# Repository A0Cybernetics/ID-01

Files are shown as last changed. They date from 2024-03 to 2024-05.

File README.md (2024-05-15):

# A0 Cybernetics: ID-01
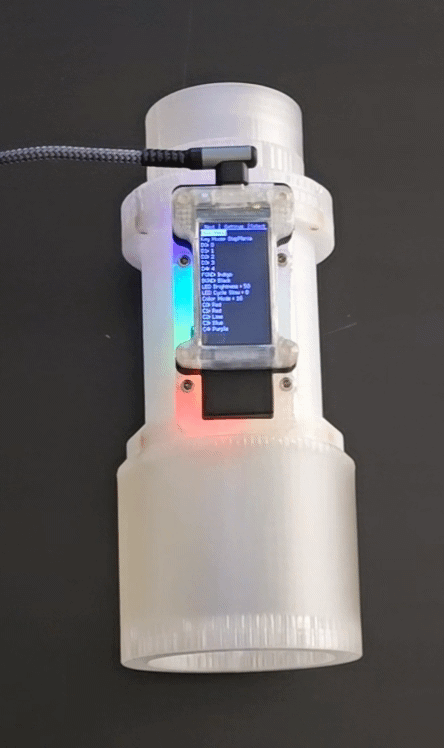
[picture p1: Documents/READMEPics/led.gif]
LEDs
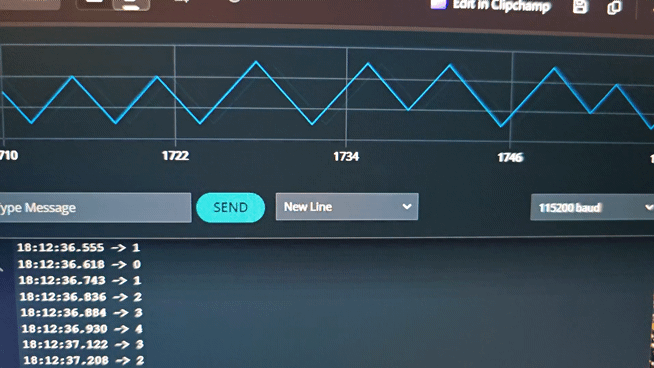
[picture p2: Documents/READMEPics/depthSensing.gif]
Depth Sensing In Action


An interactive adult entertainment device and fitness tracker. It measures a user's position within the device and can transmit commands to connected devices via USB and/or Bluetooth communication. Use data is tracked as key presses for the keys on the device, converted into XP (experience points), and can be saved over the life of the device. Build experience, control other devices, and interact with media.

- Free and open source. I do this because I like it <3

- Onboard TFT screen with UI

- Play any game. Each key can be mapped to 99 different ASCII characters in the settings.

- 21 user-customizable LED lighting modes

- Hot-swappable Cherry MK style keyboard keys for user customization

- No programming or design knowledge is necessary to build

- Open-source and reprogrammable firmware running on ESP32-S3

- Compiled binary files are provided, so there is no need to compile the program.

- Fully 3D-printed parts (except for electrical components, heat set inserts, and screws)

- Multiple designs and customization pieces are provided to accommodate sleeves from Fleshlight and other more affordable options.

- Read the [Build Guide](Documents/buildGuide.txt) for a parts list and fully detailed step-by-step instructions.

## Upgraded Fleshlight End Caps

Multiple designs are provided for end caps for this device or a regular fleshlight.

- ARRI version has a central hole pattern compatible with 1/4"-20 ARRI locating pin camera rigging equipment.

- Ultimate version has the ARRI version pattern in the center and 7 additional 1/4"-20 screw points arranged in a geometric pattern that is compatible with camera cheese plate layouts or whatever you can imagine.

- One is a replacement for the original.

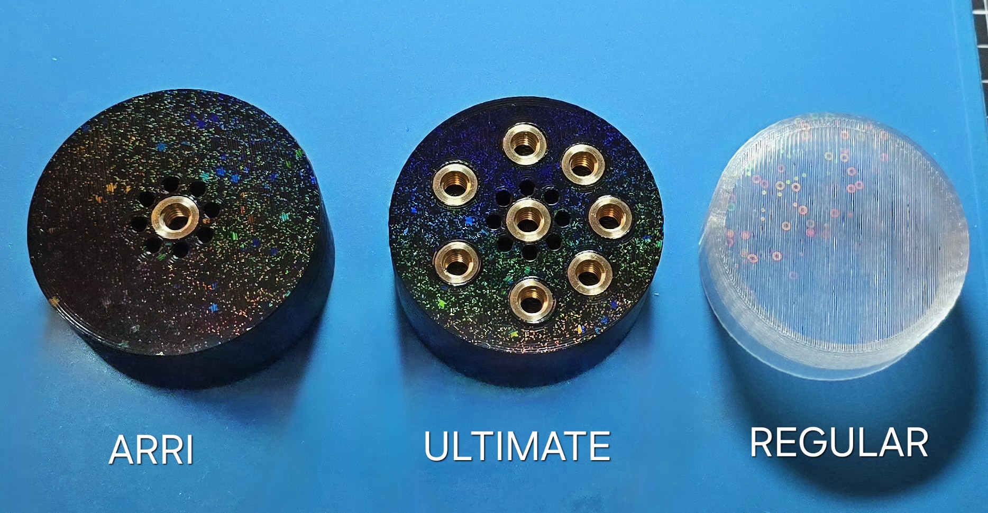
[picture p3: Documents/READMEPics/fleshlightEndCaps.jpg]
Fleshlight End Caps
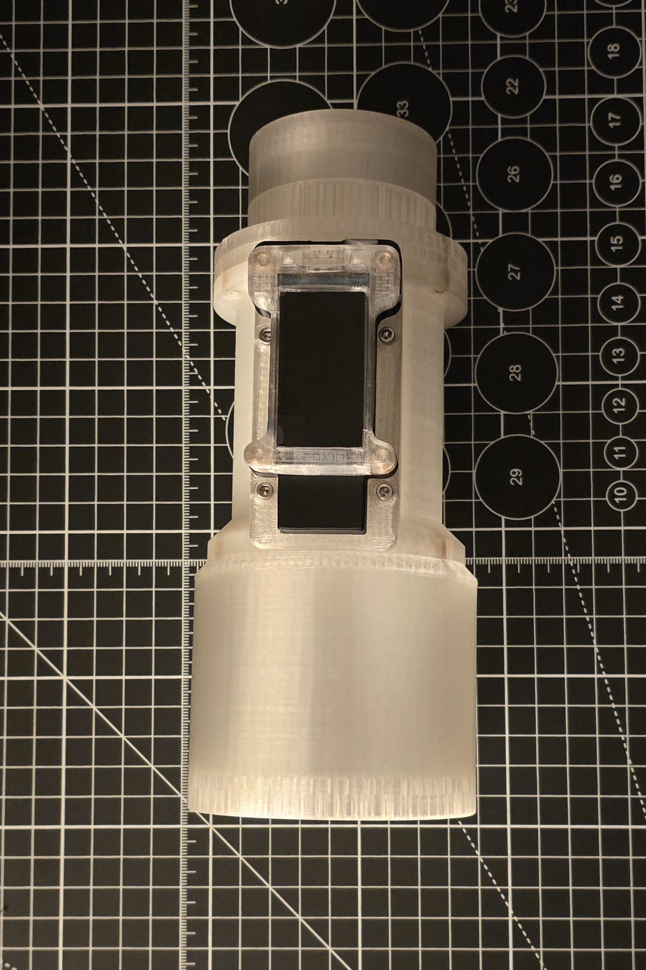
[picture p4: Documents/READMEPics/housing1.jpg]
Flesh1ight Style Housing
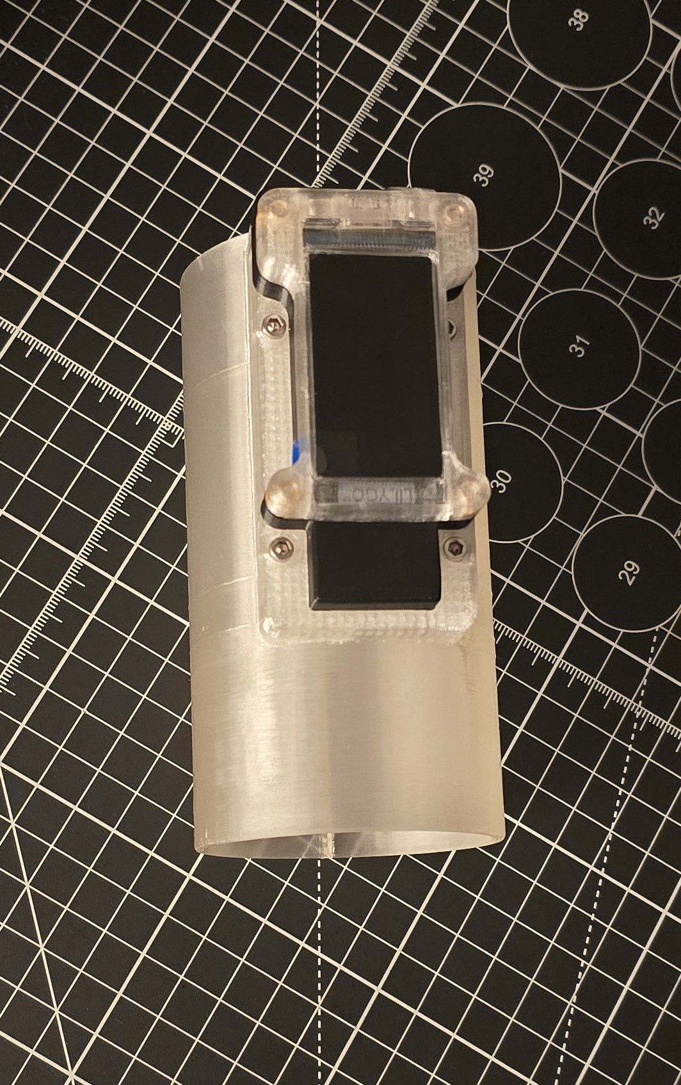
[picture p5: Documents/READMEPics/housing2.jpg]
Generic Style Housing


## Project OutFox / StepMania Compatibility

Play rhythm games with your adult toy. Insert to different depths to hit notes in sync with a rhythm game like DDR.

1. Download a version of StepMania like Project OutFox  projectoutfox.com. (no affiliation)
2. Download song packs and add them to the Project Outfox Songs folder. Search the internet for StepMania song packs.
3. Set up the game and controller as below, and most songs should be playable, but some difficult songs may be physically impossible to perform.

To use this as a controller to play Stepmania:
- On device:
	- In setting, ensure that key mode is set to StepMania. (is the default in firmware)
	- In the Main Menu, turn on BLE or USB Keyboard and connect to the computer.

- In Stepmania:
	- On the Map Controller Settings page in a device column, select the key names below then press the button on the device to map the device keys to the game keys:
		- Left -> Key 1 (most shallow key in the device)
		- Down -> Key 2
		- Up -> Key 3
		- Right -> Key 4 (deepest key in the device)
	- Calibrate Audio Sync - Select Calibrate audio sync option and complete the process to tune timing problems.
	- Set modifiers in Player Options to remove pressing more than one button at a time.
		- Press start again after selecting a song before the song starts to open the Player Options Menu
		- Navigate to the Modifiers submenu and select No Jumps on the Remove row
- Done, This will setup the game so that the notes are mapped from left/ most shallow key to right/ deepest key

## License

[MIT](https://choosealicense.com/licenses/mit/)

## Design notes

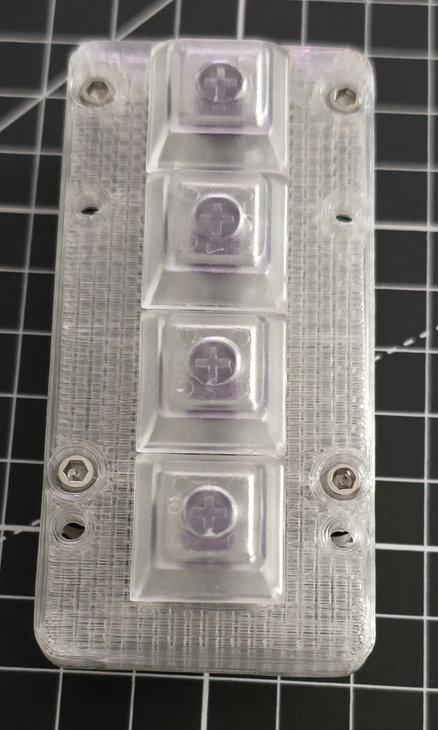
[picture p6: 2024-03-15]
Documents/buildGuidePictures/electronics7.jpg

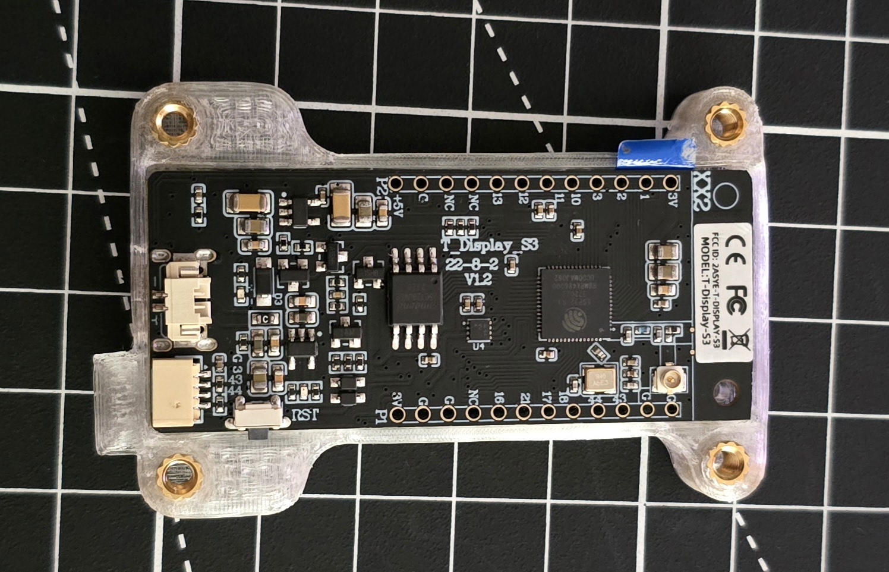
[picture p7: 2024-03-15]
Documents/buildGuidePictures/electronics2.jpg

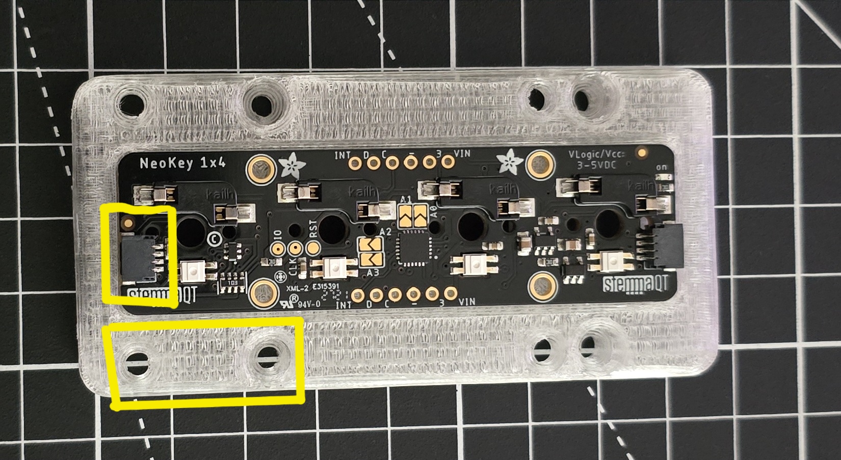
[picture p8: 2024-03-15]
Documents/buildGuidePictures/electronics3.jpg

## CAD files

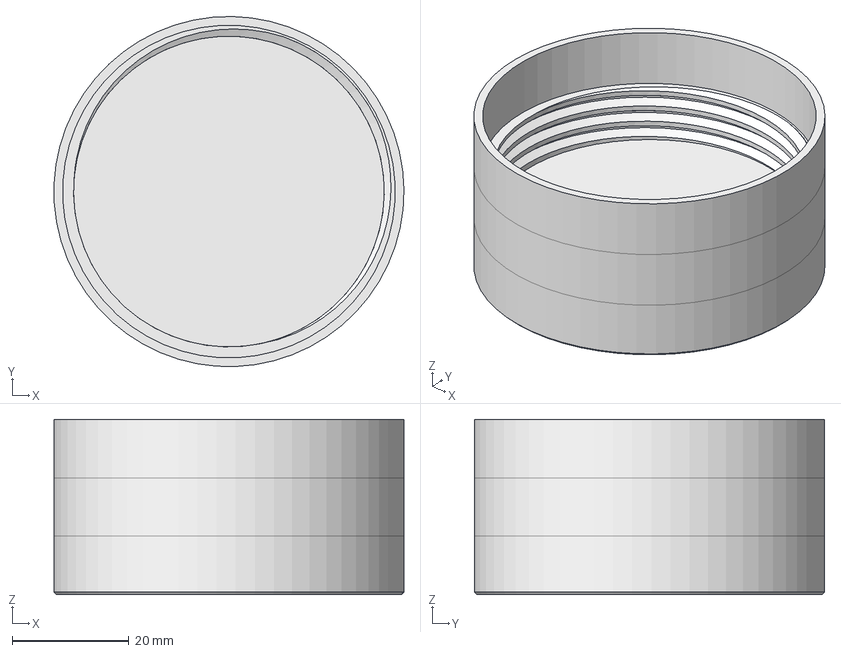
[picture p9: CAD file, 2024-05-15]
3DModels/V1.0/Adapters-FleshlightEndCaps/arriFlEndCapV1.0.FCStd
60.0 x 60.0 x 30.0 mm

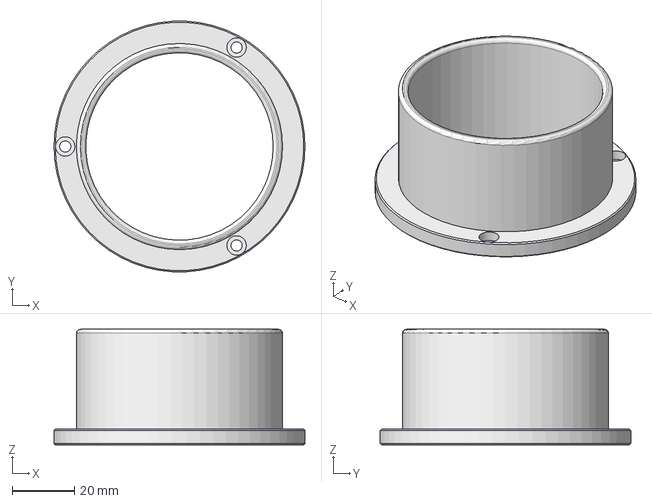
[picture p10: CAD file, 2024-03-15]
3DModels/V1.0/Adapters-Generic/adapterGenericV1.0.FCStd
80.4 x 80.3 x 37.0 mm

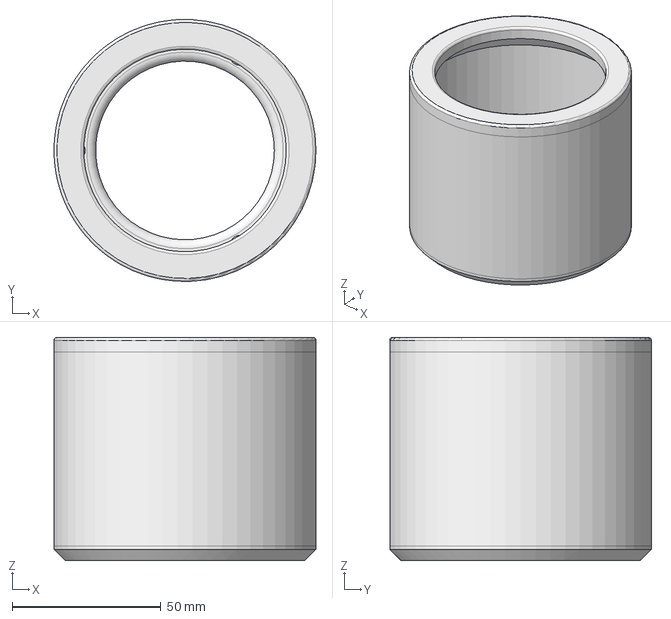
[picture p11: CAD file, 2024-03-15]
3DModels/V1.0/Adapters-LFleshlight/adapterFleshlightV1.0-75mm.FCStd
88.0 x 87.9 x 75.0 mm

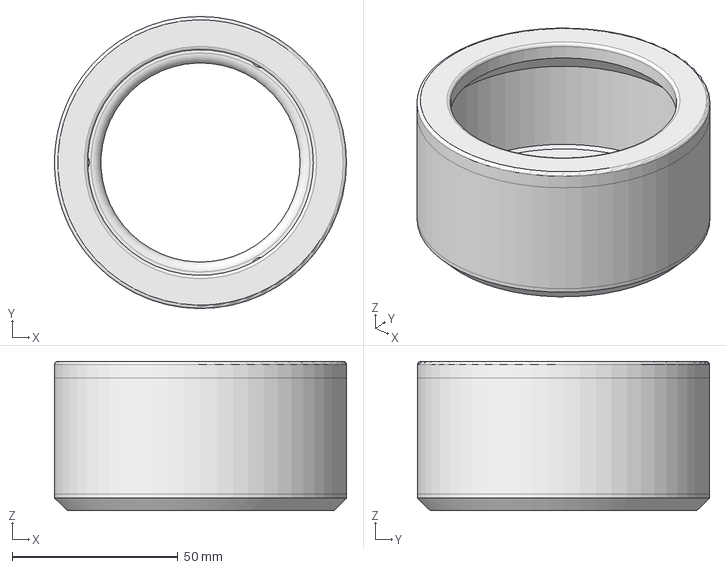
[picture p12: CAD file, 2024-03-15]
3DModels/V1.0/Adapters-MFleshlight/adapterFleshlightV1.0-45mm.FCStd
88.0 x 88.0 x 45.0 mm

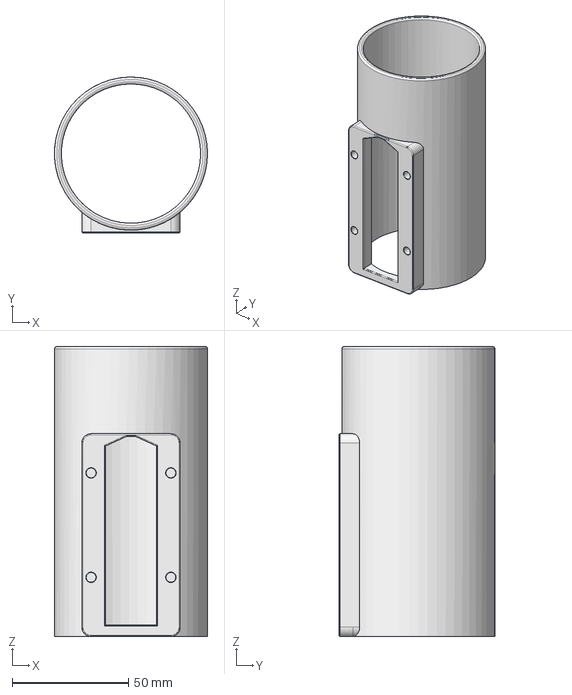
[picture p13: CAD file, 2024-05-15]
3DModels/V1.0/Barrel-Generic/barrelGenericV1.0.FCStd
66.0 x 67.2 x 125.0 mm

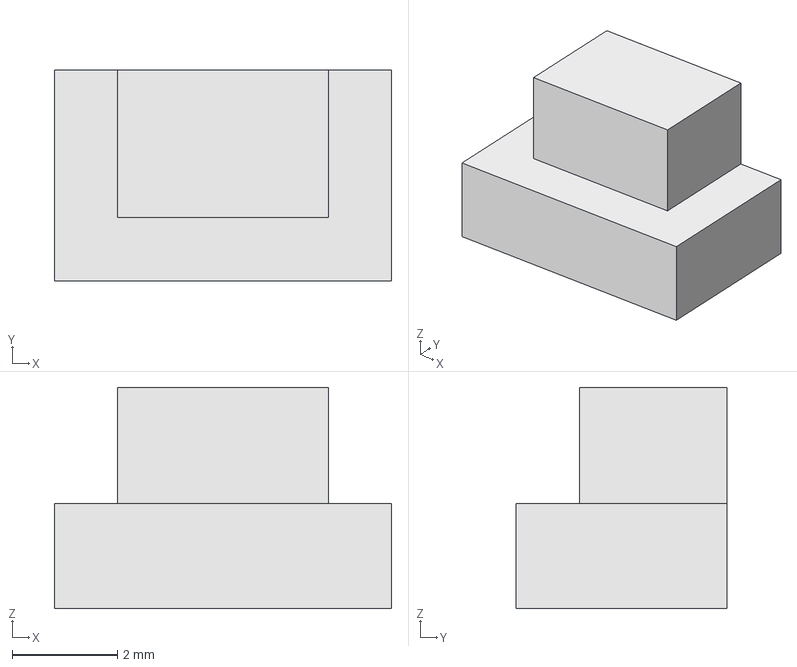
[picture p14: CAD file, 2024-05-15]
3DModels/V1.0/Buttons/navButtonV1.0.FCStd
6.40 x 4.00 x 4.20 mm

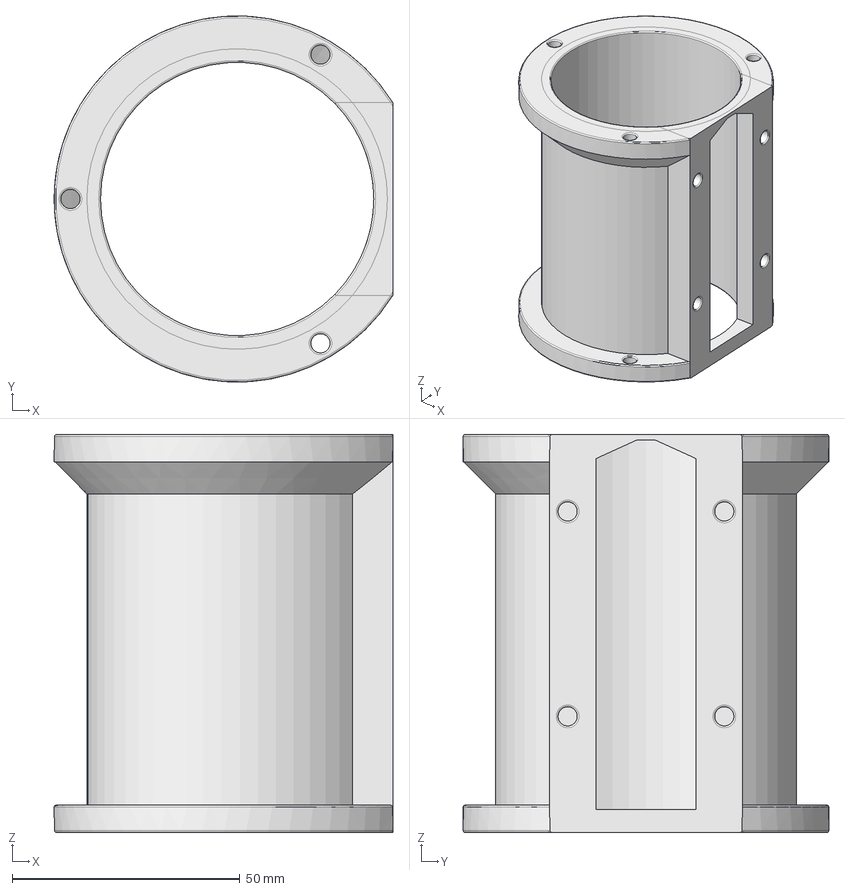
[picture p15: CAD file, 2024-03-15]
3DModels/V1.0/Core/coreV1.0.FCStd
74.4 x 80.3 x 87.4 mm

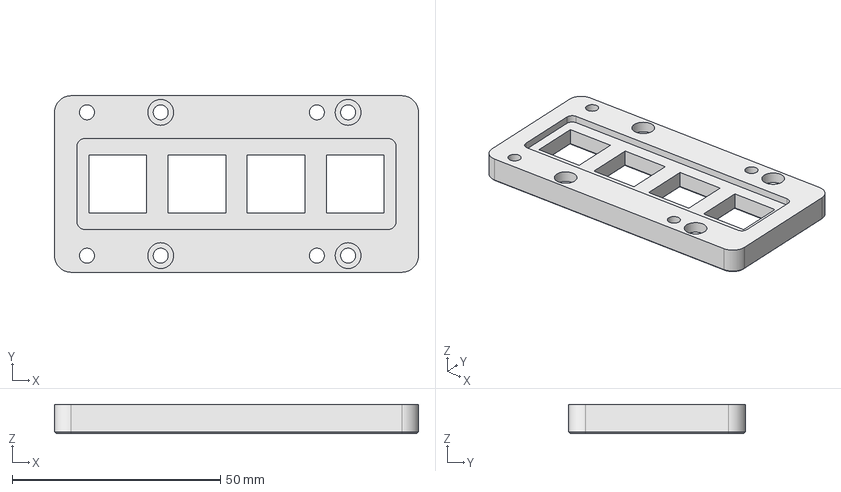
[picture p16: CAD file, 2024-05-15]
3DModels/V1.0/KeyPlate/keyPlateV1.0.FCStd
87.4 x 42.4 x 7.00 mm

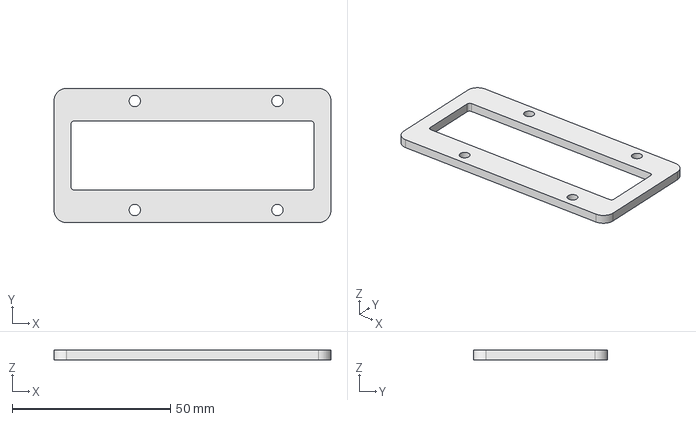
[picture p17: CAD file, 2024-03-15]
3DModels/V1.0/KeyPlateSpacers/keyPlateSpacerV1.0-3mm.FCStd
87.4 x 42.4 x 3.00 mm

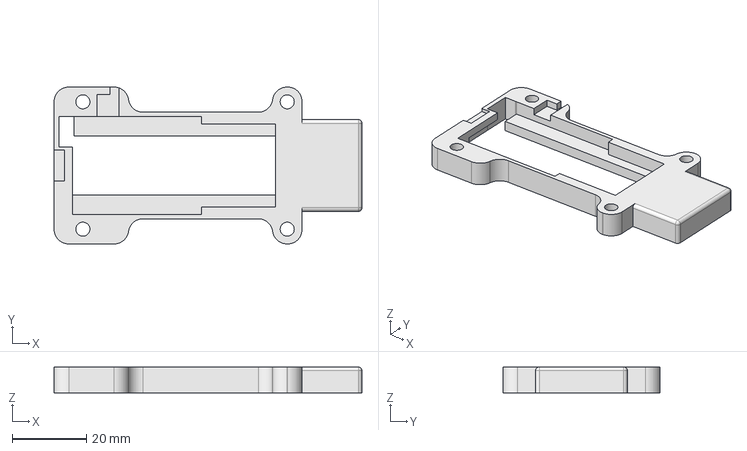
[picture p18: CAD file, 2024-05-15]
3DModels/V1.0/SpacerPlate/spacerPlateV1.0.FCStd
83.2 x 42.4 x 7.00 mm

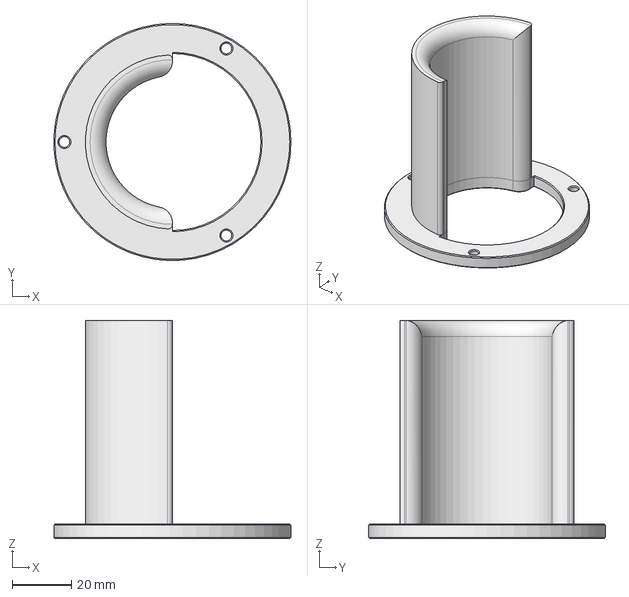
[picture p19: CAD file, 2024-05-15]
3DModels/V1.0/Stabilizers/stabilizerV1.0-45mm.FCStd
80.3 x 80.4 x 74.0 mm

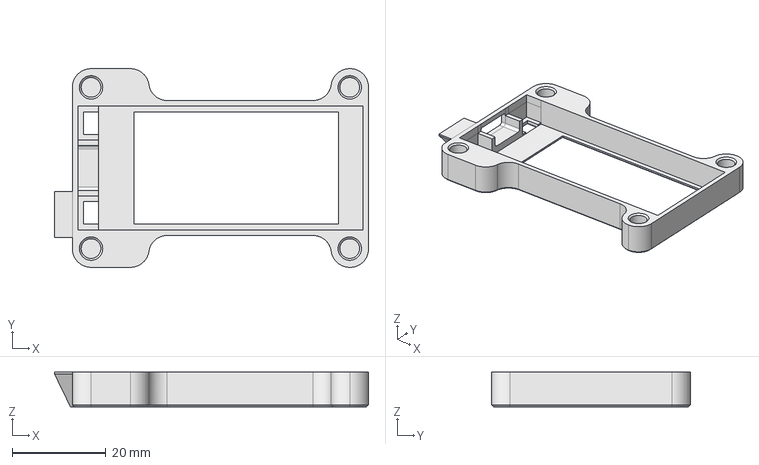
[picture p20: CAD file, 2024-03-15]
3DModels/V1.0/TopPlate/topPlateV1.0.FCStd
67.0 x 42.4 x 7.40 mm

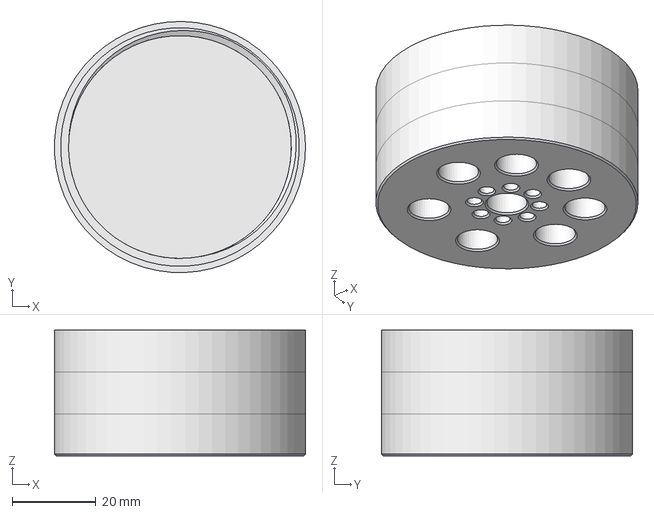
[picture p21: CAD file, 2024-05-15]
3DModels/V1.0/Adapters-FleshlightEndCaps/ultimateFlEndCapV1.0.FCStd
60.0 x 60.0 x 30.0 mm

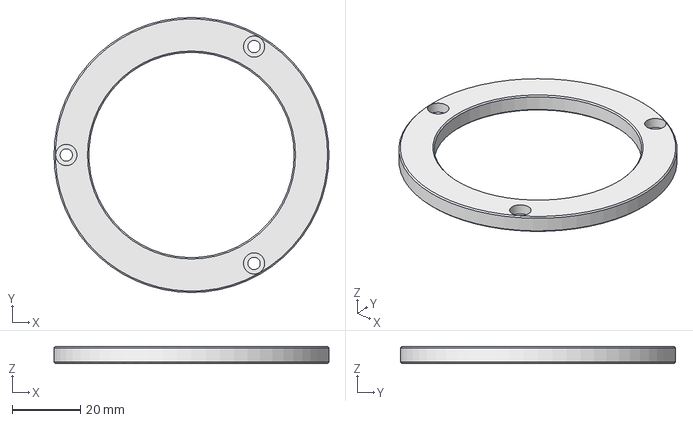
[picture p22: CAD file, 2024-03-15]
3DModels/V1.0/Adapters-Generic/retainingRingV1.0.FCStd
80.4 x 80.4 x 5.00 mm

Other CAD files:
3DModels/V1.0/Adapters-LFleshlight/endPieceFleshlightV1.0-37mm.FCStd
3DModels/V1.0/Adapters-MFleshlight/endPieceFleshlightV1.0-67mm.FCStd
3DModels/V1.0/Buttons/resetButtonV1.0.FCStd
3DModels/V1.0/KeyPlateSpacers/keyPlateSpacerV1.0-1mm.FCStd
3DModels/V1.0/Adapters-FleshlightEndCaps/arriFlEndCapV1.0.stl
3DModels/V1.0/Adapters-FleshlightEndCaps/flEndCapV1.0.FCStd
3DModels/V1.0/Adapters-FleshlightEndCaps/flEndCapV1.0.stl
3DModels/V1.0/Adapters-FleshlightEndCaps/ultimateFlEndCapV1.0.stl
3DModels/V1.0/Adapters-Generic/adapterGenericV1.0.stl
3DModels/V1.0/Adapters-Generic/retainingRingV1.0.stl
3DModels/V1.0/Adapters-LFleshlight/adapterFleshlightV1.0-75mm.stl
3DModels/V1.0/Adapters-LFleshlight/endPieceFleshlightV1.0-37mm.stl
3DModels/V1.0/Adapters-MFleshlight/adapterFleshlightV1.0-45mm.stl
3DModels/V1.0/Adapters-MFleshlight/endPieceFleshlightV1.0-67mm.stl
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

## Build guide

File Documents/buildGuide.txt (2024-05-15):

/// BUILD GUIDE

	- An interactive adult entertainment device and fitness tracker. It measures a user's position within the device and can transmit commands to connected devices via USB and/or Bluetooth communication. Use data is tracked as key presses for the keys on the device, converted into XP (experience points), and can be saved over the life of the device. Build experience, control other devices, and interact with media.

// Parts List

	1. 1 X Microcontroller Board: LILYGO T-Display-S3 Non-Soldered Pin [H569] (no touch screen, no soldered pin version) https://www.lilygo.cc/products/t-display-s3?variant=42284559827125
	2. 1 X NeoKey 1x4 QT I2C-Four Mechanical Key Switches with NeoPixels - STEMMA QT / Qwiic (Product ID: 4980) https://www.adafruit.com/product/4980
	3. 1 X Qwiic JST SH 4-pin Cable - 100mm Long https://www.adafruit.com/product/4210
	4. 4 X Keycaps for MX Compatible Switches https://www.adafruit.com/product/5068
	5. 4 X Cherry MX Style Key Switches - choose whatever kind you want - I recommend high quality, heavy actuation force, and silent switches.
	6. 8 or 14 X M3 Heat Set Inserts (5.7mm X 4.6mm dimensions) https://cnckitchen.store/products/gewindeeinsatz-threaded-insert-m3-standard-100-stk-pcs
	7. 8 or 14 x M3 Socket Head Cap Screws, 6mm - 16mm length, depending on user configuration, get a set like https://www.amazon.com/HELIFOUNER-Screws-Washers-Kit-Stainless/dp/B0BMQ5Z96H
	8. 0 - 8 X 1/4"-20 Heat Set Inserts (9.5mm X 7.6mm dimensions) like E-Z LOK TH-420-SV, or Initeq https://www.amazon.com/Z-LOK-Threaded-Plastic-Tapered/dp/B08PVQX853
	9. Print 3D-printed parts depending on the instructions below.
		- If you align the seam to the center left of the round parts, the seams should line up on the back of the device for a nicer appearance.
		- The models should print with no supports, but depending on your printer,  the Core cutout overhang, spacer plate front overhangs, and top plate USB-C cutout may come out better with support.
	10. USB-C data cable to power electronics and transmit data to connected devices

// Flashing Firmware

	1. Download Flash Download Tools from ESPRESSIF @ https://www.espressif.com/en/support/download/other-tools
	2. Run program
	3. Select ChipType: ESP32-S3; WorkMode: Develop; LoadMode: UART; OK (pic firmware1)
	4. Select firmware @ 0x0 (pic firmware2)
	5. Connect board to computer, select COM port for the board
	6. Press Start
	7. When download panel shows FINISH (pic firmware3), press reset on the board to verify download, disconnect board and close program

// Assemble Electronics Section

	/ Printed Parts List:
		1 X Top Plate
		1 X Spacer Plate
		1 X Key Plate
		1 X Reset Button
		2 X Nav Button

	/ Instructions
	1. Install 4 M3 heat set inserts into the top plate.
	2. Place the two navigation buttons in the top plate (pic electronics1).
	3. Install the T-Display board into the top plate, USB first, then press the board flush into the plate (pic electronics2).
	4. Install the Neokey Board into the key plate, paying attention to orientation, and plug the QWIIC cable into the highlighted socket (pic electronics3).
	5. Place the spacer plate over the key plate, route cable, and place the nav button into the spacer plate as shown in (pic electronics4).
	6. Plug the free end of the QWIIC cable into the T-Display and align the electronics section as shown in (pic electronics5).
	7. Flip the electronics section over and screw the assembly together with 4 X 16mm M3 screws (pic electronics6).
	8. Install key switches and keycaps (pic electronics7).
	*Electronics housing is not waterproof so keep it dry.

// Choose housing

	There are two options for housings:
	1. The quickest and easiest is the generic barrel (pic housing1) that only works with generic sleeves like (https://www.amazon.com/LeLuv-Penis-Magic-Sleeve-Pussy/dp/B0733J8QXR) and has limited adjustability (only key plate spacers), but only requires 1 3D-printed part and 4 heat set inserts.
	2. The other and best option is the modular system that works with the generic sleeves above and regular sized Fleshlights through adapters. The fit can also be customized through stabilizer adapters. (pic housing2, housing3)
		a. The housing will work with the end caps from a regular fleshlight housing. If you want to print your own version of the regular end cap, print the flEndcap (no heat set inserts required).
		b. To print an upgraded version of the endcap, choose the ARRI or ultimate end cap that work with camera rigging gear for unlimited mounting and attachment options. (pic fleshlightEndCaps)
		*ARRI - a central 1/4"-20 heat set insert surrounded by holes for ARRI locating pins. Printing the arriFlEndCap requires 1 X 1/4"-20 heat set inserts.
		*Ultimate - the ARRI end cap mounting points plus 7 surrounding heat set inserts. The additional inserts provide more mointing points, and some are spaced according to camera rigging "cheese plate" standards for even more mounting options. Printing the ultimateFlEndCap requires 8 X 1/4"-20 heat set inserts.

// Assemble Berrel-Generic Housing

	/ Printed Parts List:
		1 X Barrel-Generic
		*Optional - Key Plate Spacers for adjustment

	/ Instructions
	1. Print barrelGeneric.
	2. Install 4 X M3 Heat Set Inserts (pic housing1).
	3. Install the electronics section on the housing. Print and install Key Plate Spacers to adjust the key position (pic housing4).

// Assemble Modular System

	/ Printed Parts List:
		1 X Core
		*Whatever adapters you want

	/ Instructions
	1. Print 1 X Core
	2. Install 10 X M3 heat set inserts in holes around the core (pic housing5).

	/ Adapters
	1. Generic sleeves:
		a.Print:
			1 X Adapter Generic
			1 X Retaining Ring
			*Optional - Stabilizer for adjustment
			*Optional - Key Plate Spacers for adjustment
		b.Assembly: Screw the parts together (pic housing2).

	2. Fleshlight sleeves:
		a. Choose size based on user and highlighted sensing region M or L (pic housing6).
		b. Print:
			Files in Adapters-(M or L)Fleshlight =
			1 X Adapter Fleshlght
			1 X Fleshlight End Piece
			1 X Fleshlight End Cap (In Adapters-FleshlightEndCaps)
			*Optional - Stabilizer for adjustment
			*Optional - Key Plate Spacers for adjustment
			*Optional - End Cap
		c.Assembly: Screw the parts together (pic housing3) (pic housing7).

	/ Adjustment
		Print and install stabilizers to support the sleeve and ensure engagement with the keys while the device is in operation. This is based on the user, sleeve, and keycaps. (pic adjustment1 and adjustment2)

// Operation

	* Use navigation buttons to cycle through and select menu options.
	* Reset button restarts device
	1. Main Menu (pic operation1):
		-Session, Stats, Settings - navigate to other pages
		-BLE Keyboard - Turn Bluetooth Keyboard mode on/ pause (to turn radio completely off after turning on, reset the device)
			-Pairs as "ID-01"
			-Sends depth information as keypresses for depth as characters selected in settings
		-USB Keyboard - Turn USB Keyboard mode on/ off
			-Sends depth information as keypresses for depth as characters selected in settings
		-Serial Depth Log - Turn on/ off serial depth log mode
			-Sends depth information as an integer (0-4) to the USB-connected device's serial monitor
		-Save - Save Session XP and key press counts, update totals, and resets session data to 0
		-Saved XP and Total XP counter display

	2. Session Screen (pic operation2):
		-Main Menu - navigate to Main Menu
		-Session XP counter display
		-D1 - D4 - key press counters for depth 1 - 4 display

	3. Stats (pic operation3):
		-Main Menu - navigate to Main Menu
		-XP counters for current session, saved, and total XP (saved + session)
		-Total key press counters (session + saved)

	4. Settings (pic operation4):
		-Main Menu - navigate to Main Menu
		-D0 - D4 - select the characters sent for a depth reading
			- 0 = no key pressed, 1-4 keys in increasing depth
		-FGND - Select foreground/ text color
		-BGND - Select background color
		-LED Brightness - change the brightness of key LEDs
		-Color Mode - Select the color mode of key LEDs
		-C0 - C4 - Select colors for user-programmable color modes
		*To save changes, select Save on the Main Menu

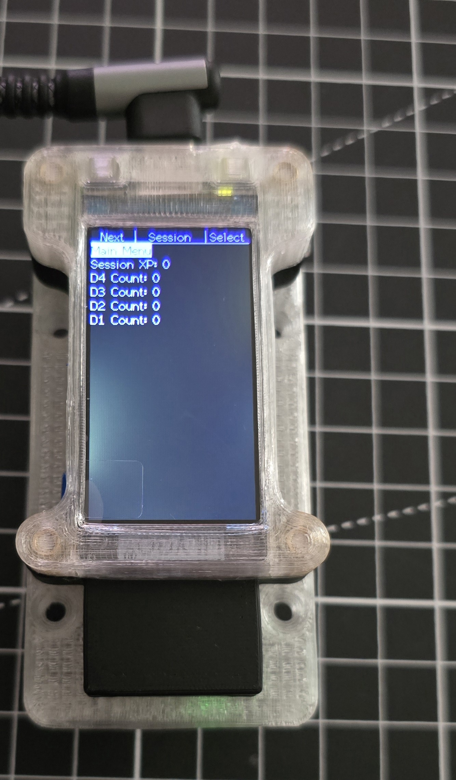
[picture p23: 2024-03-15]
Documents/buildGuidePictures/operation2.jpg

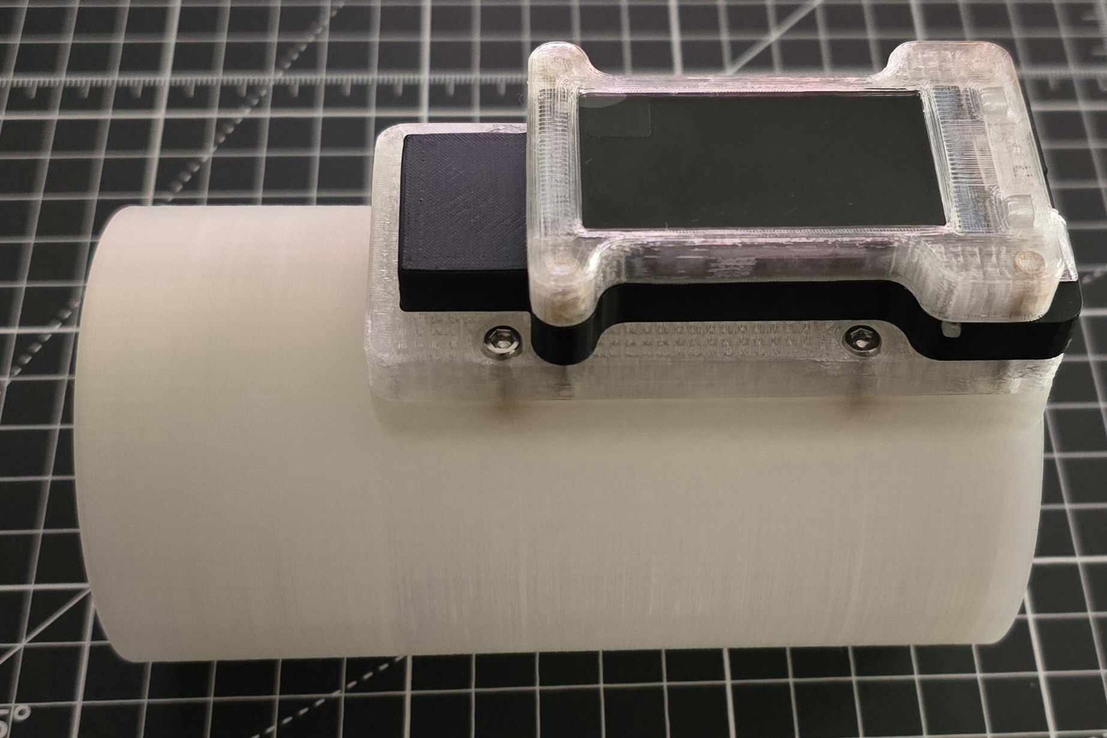
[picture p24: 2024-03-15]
Documents/buildGuidePictures/housing4.jpg

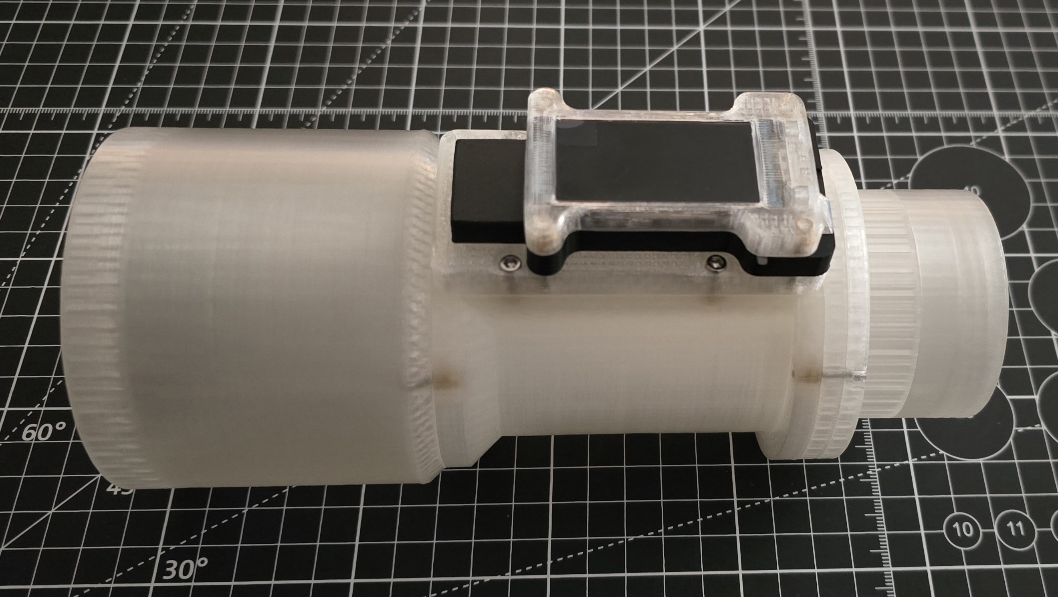
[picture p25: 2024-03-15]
Documents/buildGuidePictures/housing7.jpg

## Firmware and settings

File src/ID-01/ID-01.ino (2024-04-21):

//Screen  *have to modify User_Setup_Select.h to select board (T DIsplay S3): comment out line 27, uncomment line 133
// https://github.com/Bodmer/TFT_eSPI
#include "TFT_eSPI.h"
#include "User_Setup_Select.h"
TFT_eSPI tft = TFT_eSPI();

//Prefrences library for saving data to onboard flash
// https://github.com/espressif/arduino-esp32
// https://docs.espressif.com/projects/arduino-esp32/en/latest/api/preferences.html
#include <Preferences.h>
Preferences preferences;

// Neokey
// https://github.com/adafruit/Adafruit_Seesaw
// https://learn.adafruit.com/neokey-1x4-qt-i2c
#include "Adafruit_NeoKey_1x4.h"
#include "seesaw_neopixel.h"
Adafruit_NeoKey_1x4 Neokey;

//USB wired keyboard
// https://github.com/espressif/arduino-esp32/tree/master/libraries/USB/src
#include "USB.h"
#include "USBHIDKeyboard.h"
USBHIDKeyboard USBKeyboard;

//BLE keyboard **dependent on NIMBLE for arduino. Have to edit BleKeyboard.h to enable NIMBLE: uncomment line 2
//BLEkeyboard: https://github.com/T-vK/ESP32-BLE-Keyboard
//NIMBLE: https://github.com/h2zero/NimBLE-Arduino
#include <BleKeyboard.h>  //comment out line 37-86 and rename keyReport to BLEKeyReport to prevent conflicts with USBHIDKeyboard
BleKeyboard BLEKeyboard("ID-01", "A0", 100); //BleKeyboard bleKeyboard("Bluetooth Device Name", "Bluetooth Device Manufacturer", 100)


//QWIIC pin defs
#define PIN_QWIIC_SDA 43
#define PIN_QWIIC_SCL 44

//onboard button pin defs
#define PIN_BUTTON_1 14
#define PIN_BUTTON_2 0

//tft power pin
#define PIN_POWER_ON 15

//battery voltage analog
#define PIN_BAT_VOLT 4


void setup() {
  Serial.begin(115200);

  //setup onboard buttons
  pinMode(PIN_BUTTON_1, INPUT_PULLUP);
  pinMode(PIN_BUTTON_2, INPUT_PULLUP);

  //start wire for QWIIC I2C
  Wire.begin(PIN_QWIIC_SDA, PIN_QWIIC_SCL);
  
  //load preferences to set vars
  loadPreferences();

  //tft screen setup before others so can use screen for errors before drawing first menu
  tftSetup();
  
  //neokey Startup sequence
  neokeySetup();

  //play startup tft animation, random ~ 2-5 sec
  drawA0Animation(85, 159, 10);

  //start menu on a page.
  mainMenuSelect();
  //statsSelect();
  //settingsSelect();
  //sessionSelect();
}


void loop() {
  neokeyFn();
  menuFn();
}

/* Serial Timer
unsigned long startTime = 0;
startTime = micros();
Serial.println((String) (micros()-startTime));
*/

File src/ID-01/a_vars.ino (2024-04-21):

////////// COLOR //////////
struct color {
  String name;
  uint8_t r;
  uint8_t g;
  uint8_t b;
};

  // array 140 HTML colors color structs
const uint8_t colorArrSize = 140;
color colorArr[colorArrSize] = {	
	{"Alice Blue", 0xF0, 0xF8, 0xFF},
	{"Antique White", 0xFA, 0xEB, 0xD7},
	{"Aqua", 0x00, 0xFF, 0xFF},
	{"Aquamarine", 0x7F, 0xFF, 0xD4},
	{"Azure", 0xF0, 0xFF, 0xFF},
	{"Beige", 0xF5, 0xF5, 0xDC},
	{"Bisque", 0xFF, 0xE4, 0xC4},
	{"Black", 0x00, 0x00, 0x00},
	{"Blanched Almond", 0xFF, 0xEB, 0xCD},
	{"Blue", 0x00, 0x00, 0xFF},
	{"Blue Violet", 0x8A, 0x2B, 0xE2},
	{"Brown", 0xA5, 0x2A, 0x2A},
	{"Burly Wood", 0xDE, 0xB8, 0x87},
	{"Cadet Blue", 0x5F, 0x9E, 0xA0},
	{"Chartreuse", 0x7F, 0xFF, 0x00},
	{"Chocolate", 0xD2, 0x69, 0x1E},
	{"Coral", 0xFF, 0x7F, 0x50},
	{"Cornflower Blue", 0x64, 0x95, 0xED},
	{"Cornsilk", 0xFF, 0xF8, 0xDC},
	{"Crimson", 0xDC, 0x14, 0x3C},
	{"Cyan", 0x00, 0xFF, 0xFF},
	{"Dark Blue", 0x00, 0x00, 0x8B},
	{"Dark Cyan", 0x00, 0x8B, 0x8B},
	{"Dark Golden Rod", 0xB8, 0x86, 0x0B},
	{"Dark Gray", 0xA9, 0xA9, 0xA9},
	{"Dark Green", 0x00, 0x64, 0x00},
	{"Dark Khaki", 0xBD, 0xB7, 0x6B},
	{"Dark Magenta", 0x8B, 0x00, 0x8B},
	{"Dark Olive Green", 0x55, 0x6B, 0x2F},
	{"Dark Orange", 0xFF, 0x8C, 0x00},
	{"Dark Orchid", 0x99, 0x32, 0xCC},
	{"Dark Red", 0x8B, 0x00, 0x00},
	{"Dark Salmon", 0xE9, 0x96, 0x7A},
	{"Dark Sea Green", 0x8F, 0xBC, 0x8F},
	{"Dark Slate Blue", 0x48, 0x3D, 0x8B},
	{"Dark Sate Gray", 0x2F, 0x4F, 0x4F},
	{"Dark Turquoise", 0x00, 0xCE, 0xD1},
	{"Dark Violet", 0x94, 0x00, 0xD3},
	{"Deep Pink", 0xFF, 0x14, 0x93},
	{"Deep Sky Blue", 0x00, 0xBF, 0xFF},
	{"Dim Gray", 0x69, 0x69, 0x69},
	{"Dodger Blue", 0x1E, 0x90, 0xFF},
	{"Fire Brick", 0xB2, 0x22, 0x22},
	{"Floral White", 0xFF, 0xFA, 0xF0},
	{"Forest Green", 0x22, 0x8B, 0x22},
	{"Fuchsia", 0xFF, 0x00, 0xFF},
	{"Gainsboro", 0xDC, 0xDC, 0xDC},
	{"Ghost White", 0xF8, 0xF8, 0xFF},
	{"Gold", 0xFF, 0xD7, 0x00},
	{"Golden Rod", 0xDA, 0xA5, 0x20},
	{"Gray", 0x80, 0x80, 0x80},
	{"Green", 0x00, 0x80, 0x00},
	{"Green Yellow", 0xAD, 0xFF, 0x2F},
	{"Honey Dew", 0xF0, 0xFF, 0xF0},
	{"Hot Pink", 0xFF, 0x69, 0xB4},
	{"Indian Red", 0xCD, 0x5C, 0x5C},
	{"Indigo", 0x4B, 0x00, 0x82},
	{"Ivory", 0xFF, 0xFF, 0xF0},
	{"Khaki", 0xF0, 0xE6, 0x8C},
	{"Lavender", 0xE6, 0xE6, 0xFA},
	{"Lavender Blush", 0xFF, 0xF0, 0xF5},
	{"Lawn Green", 0x7C, 0xFC, 0x00},
	{"Lemon Chiffon", 0xFF, 0xFA, 0xCD},
	{"Light Blue", 0xAD, 0xD8, 0xE6},
	{"Light Coral", 0xF0, 0x80, 0x80},
	{"Light Cyan", 0xE0, 0xFF, 0xFF},
	{"Light Golden Rod Yellow", 0xFA, 0xFA, 0xD2},
	{"Light Gray", 0xD3, 0xD3, 0xD3},
	{"Light Green", 0x90, 0xEE, 0x90},
	{"Light Pink", 0xFF, 0xB6, 0xC1},
	{"Light Salmon", 0xFF, 0xA0, 0x7A},
	{"Light Sea Green", 0x20, 0xB2, 0xAA},
	{"Light Sky Blue", 0x87, 0xCE, 0xFA},
	{"Light Slate Gray", 0x77, 0x88, 0x99},
	{"Light Steel Blue", 0xB0, 0xC4, 0xDE},
	{"Light Yellow", 0xFF, 0xFF, 0xE0},
	{"Lime", 0x00, 0xFF, 0x00},
	{"Lime Green", 0x32, 0xCD, 0x32},
	{"Linen", 0xFA, 0xF0, 0xE6},
	{"Magenta", 0xFF, 0x00, 0xFF},
	{"Maroon", 0x80, 0x00, 0x00},
	{"Medium Aqua Marine", 0x66, 0xCD, 0xAA},
	{"Medium Blue", 0x00, 0x00, 0xCD},
	{"Medium Orchid", 0xBA, 0x55, 0xD3},
	{"Medium Purple", 0x93, 0x70, 0xDB},
	{"Medium Sea Green", 0x3C, 0xB3, 0x71},
	{"Medium Slate Blue", 0x7B, 0x68, 0xEE},
	{"Medium Spring Green", 0x00, 0xFA, 0x9A},
	{"Medium Turquoise", 0x48, 0xD1, 0xCC},
	{"Medium Violet Red", 0xC7, 0x15, 0x85},
	{"Midnight Blue", 0x19, 0x19, 0x70},
	{"Mint Cream", 0xF5, 0xFF, 0xFA},
	{"Misty Rose", 0xFF, 0xE4, 0xE1},
	{"Moccasin", 0xFF, 0xE4, 0xB5},
	{"Navajo White", 0xFF, 0xDE, 0xAD},
	{"Navy", 0x00, 0x00, 0x80},
	{"Old Lace", 0xFD, 0xF5, 0xE6},
	{"Olive", 0x80, 0x80, 0x00},
	{"Olive Drab", 0x6B, 0x8E, 0x23},
	{"Orange", 0xFF, 0xA5, 0x00},
	{"Orange Red", 0xFF, 0x45, 0x00},
	{"Orchid", 0xDA, 0x70, 0xD6},
	{"Pale Golden Rod", 0xEE, 0xE8, 0xAA},
	{"Pale Green", 0x98, 0xFB, 0x98},
	{"Pale Turquoise", 0xAF, 0xEE, 0xEE},
	{"Pale Violet Red", 0xDB, 0x70, 0x93},
	{"Papaya Whip", 0xFF, 0xEF, 0xD5},
	{"Peach Puff", 0xFF, 0xDA, 0xB9},
	{"Peru", 0xCD, 0x85, 0x3F},
	{"Pink", 0xFF, 0xC0, 0xCB},
	{"Plum", 0xDD, 0xA0, 0xDD},
	{"Powder Blue", 0xB0, 0xE0, 0xE6},
	{"Purple", 0x80, 0x00, 0x80},
	{"Red", 0xFF, 0x00, 0x00},
	{"Rosy Brown", 0xBC, 0x8F, 0x8F},
	{"Royal Blue", 0x41, 0x69, 0xE1},
	{"Saddle Brown", 0x8B, 0x45, 0x13},
	{"Salmon", 0xFA, 0x80, 0x72},
	{"Sandy Brown", 0xF4, 0xA4, 0x60},
	{"Sea Green", 0x2E, 0x8B, 0x57},
	{"Sea Shell", 0xFF, 0xF5, 0xEE},
	{"Sienna", 0xA0, 0x52, 0x2D},
	{"Silver", 0xC0, 0xC0, 0xC0},
	{"Sky Blue", 0x87, 0xCE, 0xEB},
	{"Slate Blue", 0x6A, 0x5A, 0xCD},
	{"Slate Gray", 0x70, 0x80, 0x90},
	{"Snow", 0xFF, 0xFA, 0xFA},
	{"Spring Green", 0x00, 0xFF, 0x7F},
	{"Steel Blue", 0x46, 0x82, 0xB4},
	{"Tan", 0xD2, 0xB4, 0x8C},
	{"Teal", 0x00, 0x80, 0x80},
	{"Thistle", 0xD8, 0xBF, 0xD8},
	{"Tomato", 0xFF, 0x63, 0x47},
	{"Turquoise", 0x40, 0xE0, 0xD0},
	{"Violet", 0xEE, 0x82, 0xEE},
	{"Wheat", 0xF5, 0xDE, 0xB3},
	{"White", 0xFF, 0xFF, 0xFF},
	{"White Smoke", 0xF5, 0xF5, 0xF5},
	{"Yellow", 0xFF, 0xFF, 0x00},
	{"Yellow Green", 0x9A, 0xCD, 0x32},
};

  //stores indexes of colorArray  raw color structs for key colors
  //0 for solid colors, 1-4 for individual key colors
const uint8_t neokeyColorArrSize = 5;
uint8_t neokeyColorArr[neokeyColorArrSize] = {113, 113, 76, 9, 112};  //76 lime 113 red 9 blue 112 purple
  //stores colors from keyColorArray converted to 32bit colors for neokey initialized in startupNeokey
  //updateKeyRGB32Bright(brightness) converts key color array to 32bit color array adjusted for 0-100 brightness
uint32_t keyRGB32BrightColorArr[neokeyColorArrSize] = {};

////////// NEOKEY //////////
uint16_t numKeys = 4;   //  stores number of neopixels / buttons should be 4 after numPixels = neokey.pixels.numPixels(); in startup

  //store ascii char that can be sent from keyboard 0-94 printed on display for select menu
  //i94= space, i95 = KEY_RIGHT_ARROW, i96 = KEY_LEFT_ARROW, i97= KEY_DOWN_ARROW, i98 = KEY_UP_ARROW
const uint8_t asciiCharArrSize = 99;
const char asciiCharArr[asciiCharArrSize]= {'!','\"','#','$','%','&','\'','(',')','*','+',',','-','.','/','0','1','2','3','4','5','6','7','8','9',':',';','<','=','>','?','@','A','B','C','D','E','F','G','H','I','J','K','L','M','N','O','P','Q','R','S','T','U','V','W','X','Y','Z','[','\\',']','^','_','`','a','b','c','d','e','f','g','h','i','j','k','l','m','n','o','p','q','r','s','t','u','v','w','x','y','z','{','|','}','~',' ',0xD7/*215right*/,0xD8/*216left*/,0xD9/*217down*/,0xDA/*218up*/};
  //store selected chars for 0 - 4 depth/keys
uint8_t depthCharArr[5] = {93, 93, 93, 93, 93}; //{15, 16, 17, 18, 19}; //array storing char sent for 0 depth (0) and keys (1-4) /depth 1-4
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

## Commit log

2024-03-23 Updated src and firmware
    General improvements, added speed control for led animations
2024-05-15 Delete 3DModels directory
    switching to .stl
    [adapterFleshlightV1.0-45mm.3mf, adapterFleshlightV1.0-45mm.FCStd, adapterFleshlightV1.0-75mm.3mf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]
2024-05-15 switched to .stl
    [adapterFleshlightV1.0-45mm.FCStd, adapterFleshlightV1.0-45mm.stl, adapterFleshlightV1.0-75mm.FCStd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]
